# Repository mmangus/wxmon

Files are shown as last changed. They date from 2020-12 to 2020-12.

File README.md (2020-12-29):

# wxmon
Weather monitor using the ESP12E MCU and BME280 environmental sensor, comprised of an outdoor solar-powered sensor module and an indoor eInk display module. Optimized for low power consumption, draws only ~30μA while sleeping.

## Sensor module
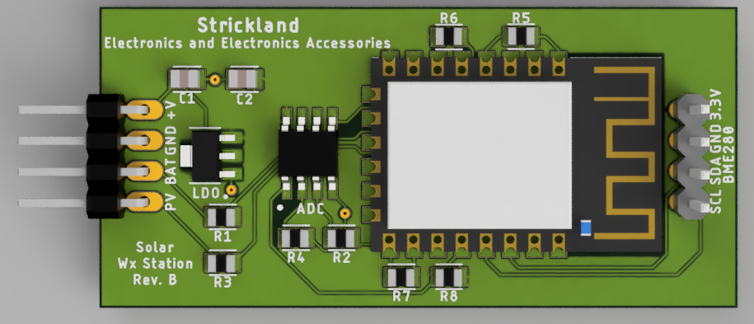
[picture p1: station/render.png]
Render

### Progress
- [X] Schematic
- [X] PCB Layout
- [X] Gerber CAM files (zipped up and ready to upload to JLC PCB, OSH Park, etc)
- [ ] Software created using PlatformIO/Arduino - WIP
- [ ] Enclosure STL files

## Display module
### Progress
- [ ] Schematic
- [ ] PCB Layout
- [ ] Gerber CAM files (zipped up and ready to upload to JLC PCB, OSH Park, etc)
- [ ] Software created using PlatformIO/Arduino
- [ ] Enclosure STL files

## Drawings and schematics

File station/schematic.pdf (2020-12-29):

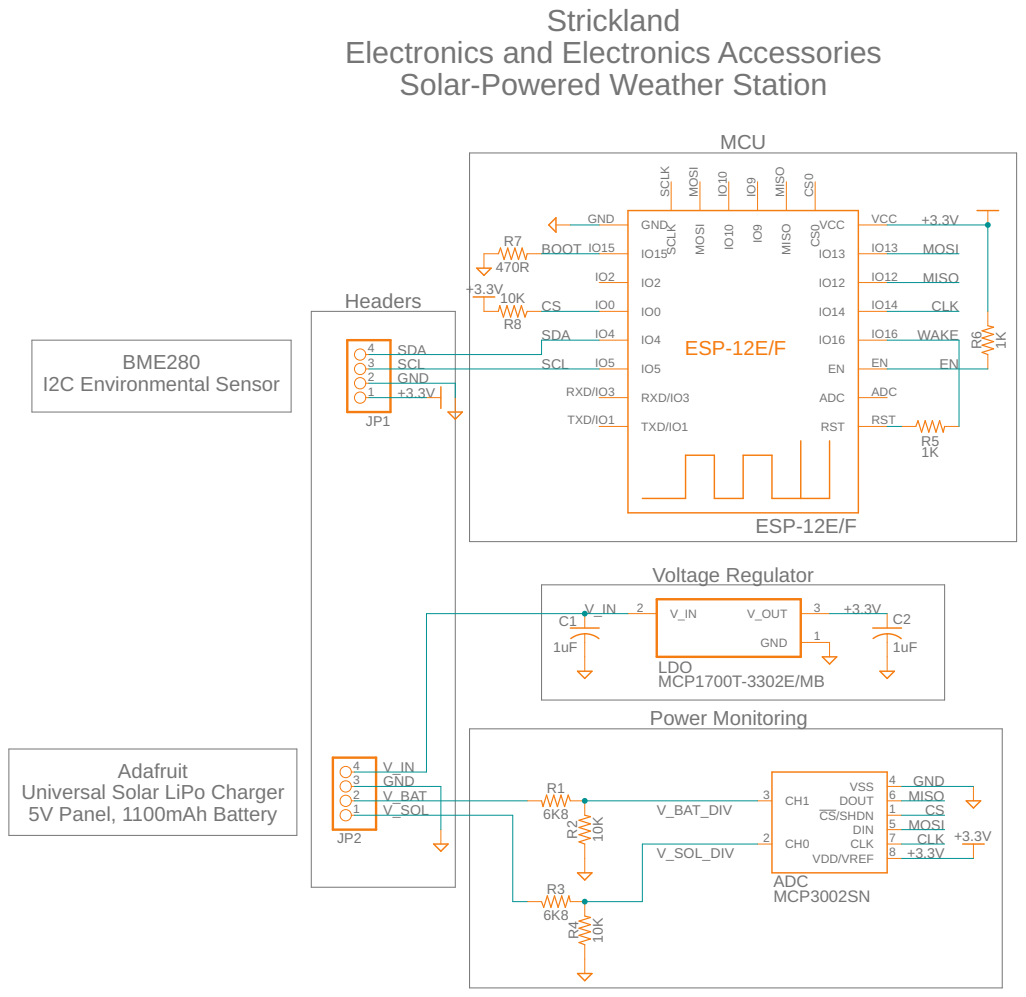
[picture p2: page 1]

Electronics and Electronics Accessories
Solar-Powered Weather Station

Universal Solar LiPo Charger
5V Panel, 1100mAh Battery

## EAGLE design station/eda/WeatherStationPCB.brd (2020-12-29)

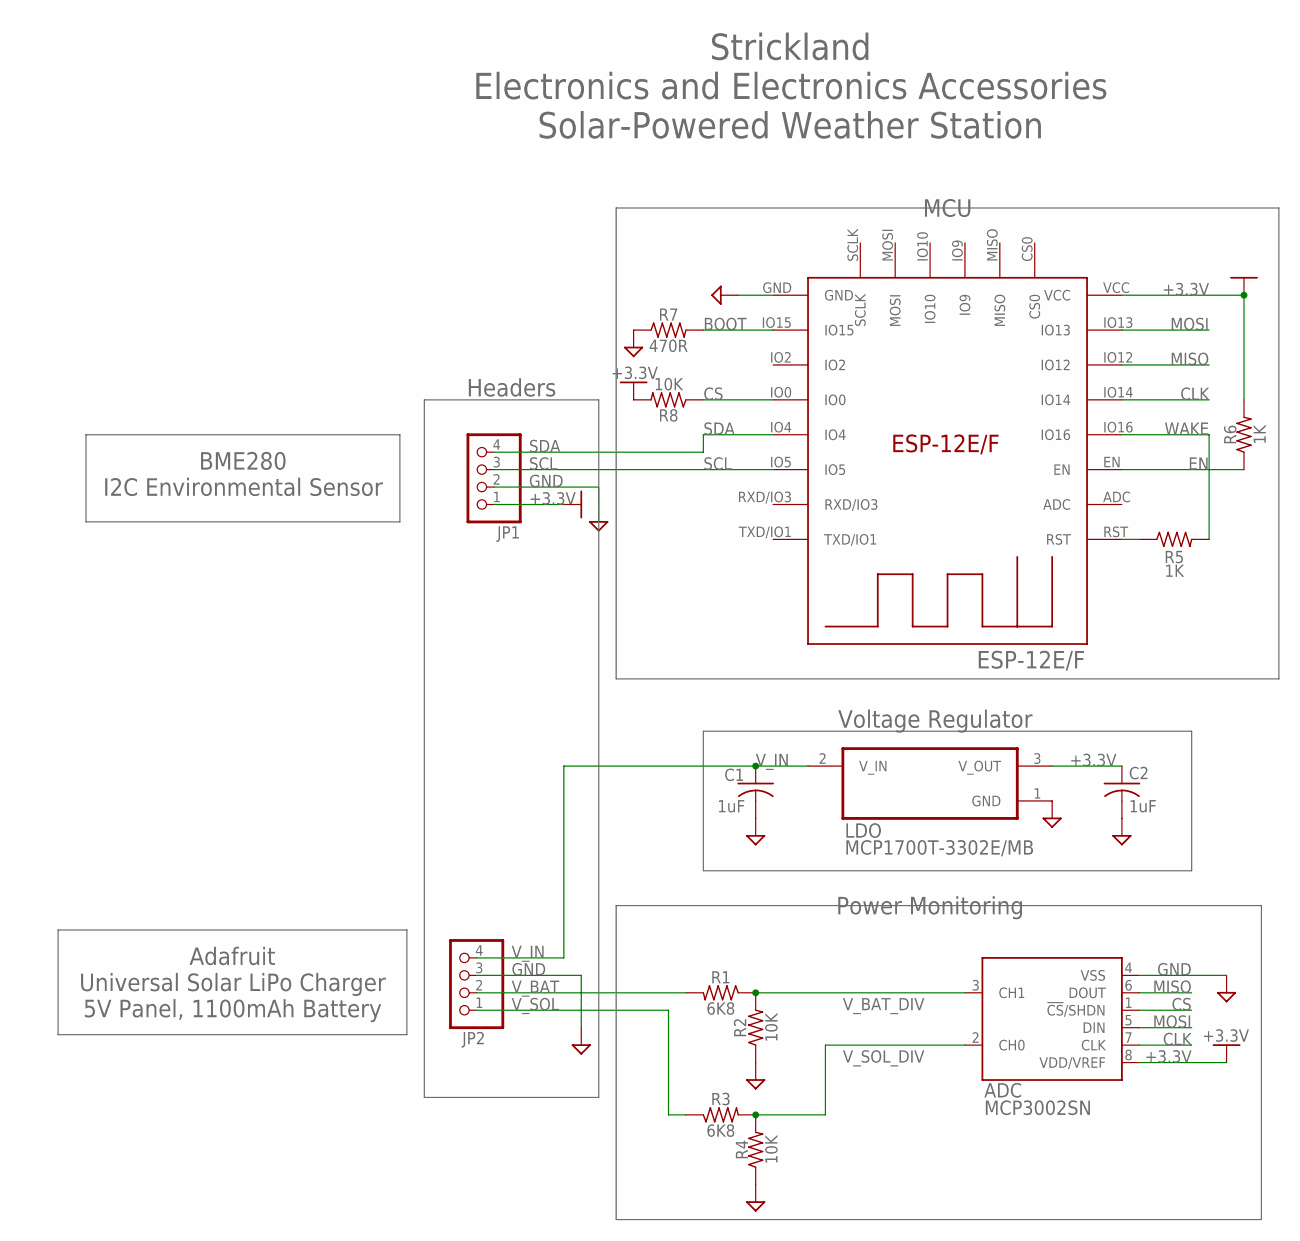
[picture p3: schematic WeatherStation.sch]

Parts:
ADC: MCP3002SN; SO-08
C1, C2: 1uF; CAPC2012X110
IC1: ESP-12E/F; ESP-12E
JP1: PINHD-1X4; 1X04
JP2: PINHD-1X4/90; 1X04/90
LDO: MCP1700T-3302E/MB; REG-MCP1700TA-4P6X2P6-3SM-H1P6
R1, R3: 6K8; RESC2012X65
R2, R4, R8: 10K; RESC2012X65
R5, R6: 1K; RESC2012X65
R7: 470R; RESC2012X65

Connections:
+3.3V: ADC.8 (VDD/VREF), C2.1, IC1.VCC, JP1.1, LDO.3 (V_OUT), R6.2, R8.2
BOOT: IC1.IO15, R7.2
CLK: ADC.7 (CLK), IC1.IO14
CS: ADC.1 (!CS!/SHDN), IC1.IO0, R8.1
EN: IC1.EN, R6.1
GND: ADC.4 (VSS), C1.2, C2.2, IC1.GND, JP1.2, JP2.3, LDO.1 (GND), R2.1, R4.1, R7.1
MISO: ADC.6 (DOUT), IC1.IO12
MOSI: ADC.5 (DIN), IC1.IO13
RST: IC1.RST, R5.1
SCL: IC1.IO5, JP1.3
SDA: IC1.IO4, JP1.4
V_BAT: JP2.2, R1.2
V_BAT_DIV: ADC.3 (CH1), R1.1, R2.2
V_IN: C1.1, JP2.4, LDO.2 (V_IN)
V_SOL: JP2.1, R3.1
V_SOL_DIV: ADC.2 (CH0), R3.2, R4.2
WAKE: IC1.IO16, R5.2

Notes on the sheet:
Voltage Regulator
Power Monitoring
MCU
Headers
Strickland Electronics and Electronics Accessories Solar-Powered Weather Station
BME280 I2C Environmental Sensor
Adafruit Universal Solar LiPo Charger 5V Panel, 1100mAh Battery

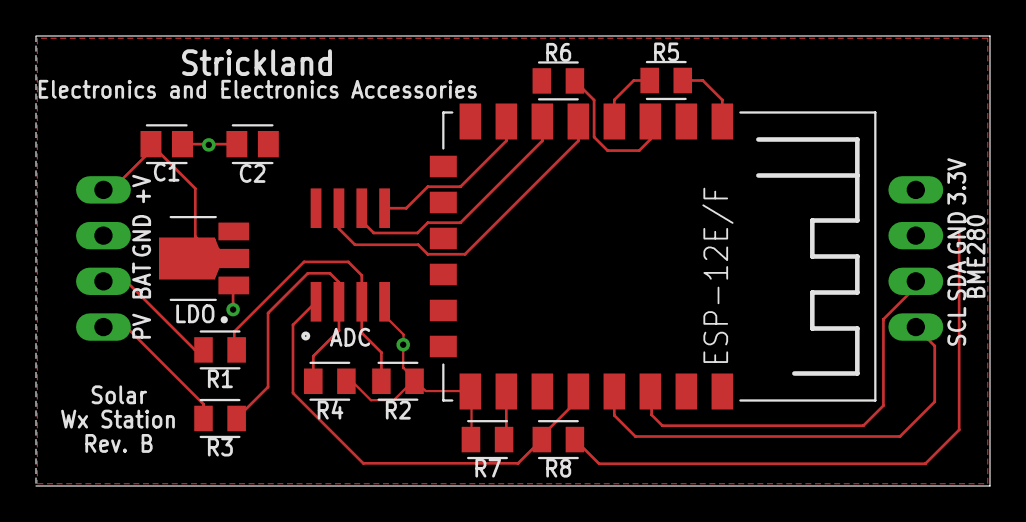
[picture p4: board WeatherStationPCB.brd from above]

Board: 2 copper layers, 53.0 x 25.0 mm, 15 parts (0 on the bottom side), 17 nets.

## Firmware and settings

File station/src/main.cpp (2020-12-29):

#include <Adafruit_Sensor.h>
#include <Adafruit_BME280.h>
#include <ESP8266mDNS.h>
#include <ESP8266WiFi.h>
#include <ESP8266WebServer.h>
#include <ESP8266HTTPUpdateServer.h>
#include <MCP3XXX.h>
#include <NTPClient.h>
#include <WiFiUdp.h>
#include <Wire.h>

#include <../../display/src/display.h>  // configuration loaded from header

#define WAKEUP_INTERVAL_US 3e8  // 5 minutes


Adafruit_BME280 bme;
MCP3002 mcp3002;
WiFiClient wifiSerial;
WiFiUDP ntpUDP;
NTPClient timeClient(ntpUDP);
ESP8266WebServer httpServer(80);
ESP8266HTTPUpdateServer httpUpdater;


void setup()
{ 
  Serial.begin(9600);

  pinMode(LED_BUILTIN, OUTPUT);
  WiFi.hostname("wxsta");
  WiFi.begin(DISPLAY_SSID, DISPLAY_PASSWORD);
  while (WiFi.status() != WL_CONNECTED) {
    digitalWrite(LED_BUILTIN, LOW);
    delay(100);
  }
  digitalWrite(LED_BUILTIN, HIGH);

  timeClient.begin();
  uint32 sleptFor = 0;
  uint32 lastTime;
  timeClient.update();
  uint32 epochTime = timeClient.getEpochTime();
  if (ESP.getResetInfoPtr()->reason == REASON_DEEP_SLEEP_AWAKE) 
  {
    ESP.rtcUserMemoryRead(0, &lastTime, sizeof(lastTime));
    ESP.rtcUserMemoryWrite(0,  &epochTime, sizeof(epochTime));
    sleptFor = epochTime - lastTime - millis() / 1000.;
  }
  
  if (!wifiSerial.connected()) {
    wifiSerial.stop();
    wifiSerial.connect("fossil.local", 3000);
  }

  httpUpdater.setup(&httpServer);
  httpServer.begin();

  MDNS.begin("wxsta");
  MDNS.addService("http", "tcp", 80);

  bme.begin(0x76);
  bme.setSampling(  // use recommended settings for low-power weather monitoring
    bme.MODE_FORCED,  // sleep after each reading
    bme.SAMPLING_X1,  // temperature 1x oversample
    bme.SAMPLING_X1,  // pressure 1x oversample
    bme.SAMPLING_X1,  // humidity 1x oversample
    bme.FILTER_OFF,   // no IIR filtering
    bme.STANDBY_MS_1000  // 1 sec standby duration (don't think this matters in forced mode?)
  );
  
  mcp3002.begin(0);  // move SPI CS pin to GPIO0 so it can pull high (GPIO15 must pull low)
 
  float temp = bme.readTemperature();
  float press = bme.readPressure() / 100.f;
  float humidity = bme.readHumidity();
  
  float ch0 = mcp3002.analogRead(0) / 1023.f * 100.f;
  float ch1 = mcp3002.analogRead(1) / 1023.f * 100.f;

  wifiSerial.println("********************");
  wifiSerial.println(timeClient.getFormattedTime());
  wifiSerial.printf("CH0      = %.2f%%\n", ch0);
  wifiSerial.printf("CH1      = %.2f%%\n", ch1);
  wifiSerial.printf("Temp.    = %.2f *C\n", temp);
  wifiSerial.printf("Pressure = %.2f hPa\n", press); 
  wifiSerial.printf("Humidity = %.2f%%\n", humidity);
  wifiSerial.printf("%d seconds since last reading\n", sleptFor); // TODO
  wifiSerial.stop();
  delay(250); // this delay seems to solve recon issues, check for serial stop instead?
  //httpServer.handleClient();
  //delay(10 * 1000);
  // TODO calibrate?
  ESP.deepSleep(WAKEUP_INTERVAL_US - micros());
}

void loop() {};
